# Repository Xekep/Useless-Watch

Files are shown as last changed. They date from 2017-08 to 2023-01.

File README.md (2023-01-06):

Watch the video (https://www.youtube.com/watch?v=YxNCa986Xg4)

# Useless-Watch — Часы c GPS модулем.

## Особенности

* Настройка часового пояса сохраняется в энергонезависимую память часов (часы нет необходимости настраивать при каждом включении).
* Синхронизация времени по GPS происходит раз в час и при смене часового пояса, а также при включении часов.
* В режиме настройки можно выбрать только российские часовые пояса (от +2 — Калининградская область до +12 — Камчатский край).

## Режимы работы

### Настройка часового пояса

Нажатие кнопки №1 переводит часы в режим настройки часового пояса или отображения времени. В режиме настройки на дисплее отображается смещение времени по шкале UTC, а последующие нажатия кнопки №2 приводят к циклическому инкременту часового пояса (от +2 до +12).

### Режим отображения секунд

Нажатие кнопки №2 переводит часы в режим отображения секунд и сантисекунд.

## Электрическая схема

Схема запитывается от 5В и защищена от: перенапряжения, короткого замыкания, переполюсовки.

### Компонентная база

* Макетная плата 5x7см — 3шт.
* Гнездо для ИС — 3шт.
* Гнездо на плату 2.54мм — 4шт.
* Датчик наклона SW-200D — 2шт.
* Защитный диод SA5.0A — 1шт.
* Керамический дисковый конденсатор 0.01мкФ — 1шт.
* Керамический дисковый конденсатор 0.1мкФ — 9шт.
* Керамический дисковый конденсатор 22пФ — 2шт.
* Микроконтроллер ATmega328P-PU — 1шт.
* Модуль GPS NEO6MV2 — 1шт.
* Предохранитель 0.16А — 1шт.
* Разъем Micro-USB DIP — 1шт.
* Резистор 10кОм — 1шт.
* Резистор 1кОм — 8шт.
* Сдвиговый регистр 74HC595 — 2шт.
* Семисегментный индикатор CL5642BH-33 — 1шт.
* Транзистор BS170 — 1шт.
* Угловая тактовая кнопка 3.85мм — 2шт.
* Часовой кварцевый резонатор 32768Гц — 1шт.
* Штырьевая вилка на плату 2.54мм — 4шт.
* Электролитический конденсатор 1000мкФ — 1шт.

## Корпусирование

### Детали корпуса

* Шайба М3 — 24шт.  
* Винт М3 — 8шт.  
* Cтойка для плат М3 10мм — 16шт.  
* Плексиглас

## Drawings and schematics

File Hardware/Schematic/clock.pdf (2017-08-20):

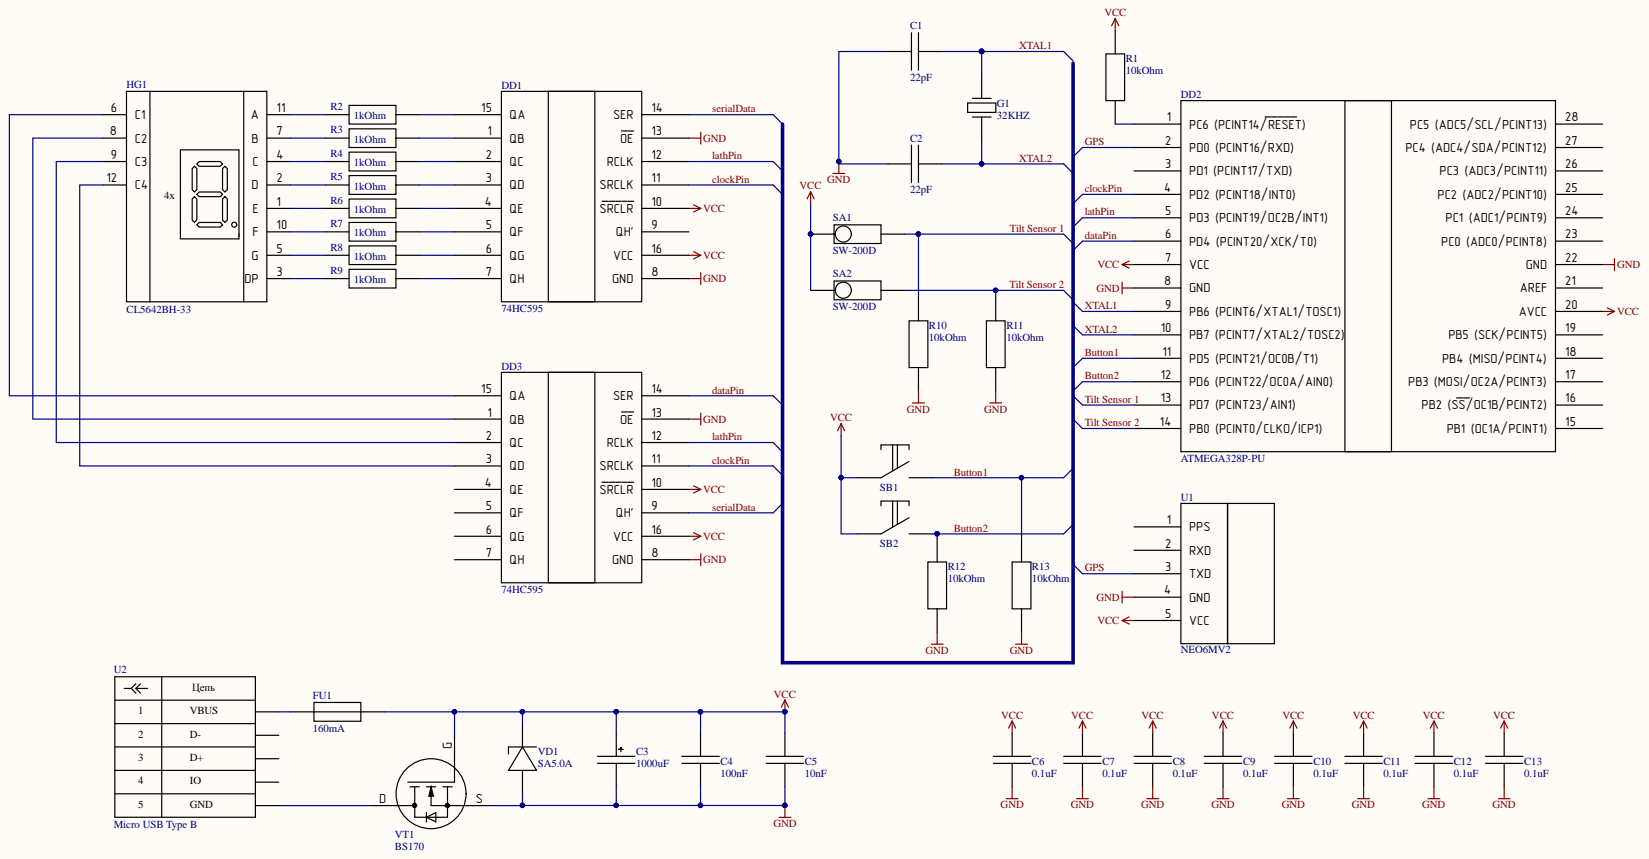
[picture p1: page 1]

C4 12 | | D | 2 | 1kOhm R5 | QD 3

E | 1 | 1kOhm R6 | QE 4 QF 5 QG 6

Цепь

1 | VBUS

5 | GND

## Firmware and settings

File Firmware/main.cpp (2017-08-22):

#include <avr/io.h>
#include <util/delay.h>
#include <avr/interrupt.h>
#include <avr/eeprom.h>
#include <string.h>
#include <stdlib.h>
#include "settings.h"


enum clockMode { clockTime, clockSetTimezone, clockSeconds };
enum displayMode { displayNormal, displayFlipped };
enum segments { A, B, C, D, E, F, G, DP };

uint8_t displayDigits[][4] = { { displayDigit1, displayDigit2, displayDigit3, displayDigit4 },
			       { displayDigit4, displayDigit3, displayDigit2, displayDigit1 } };

uint8_t symbols[][10] = { { zero, one, two, three, four, five, six, seven, eight, nine },
			  { zero_flipped, one_flipped, two_flipped, three_flipped, four_flipped, five_flipped, six_flipped, seven_flipped, eight_flipped, nine_flipped } };

uint8_t hello[][10][4] = {
				{
					{ minus, minus, minus, minus },
					{ symbol_H, minus, minus, minus },
					{ symbol_E, symbol_H, minus, minus },
					{ symbol_L, symbol_E, symbol_H, minus },
					{ symbol_L, symbol_L, symbol_E, symbol_H },
					{ symbol_O, symbol_L, symbol_L, symbol_E },
					{ minus, symbol_O, symbol_L, symbol_L },
					{ minus, minus, symbol_O, symbol_L },
					{ minus, minus, minus, symbol_O },
					{ minus, minus, minus, minus }
				},
				{
					{ minus, minus, minus, minus },
					{ symbol_H_flipped, minus, minus, minus },
					{ symbol_E_flipped, symbol_H_flipped, minus, minus },
					{ symbol_L_flipped, symbol_E_flipped, symbol_H_flipped, minus },
					{ symbol_L_flipped, symbol_L_flipped, symbol_E_flipped, symbol_H_flipped },
					{ symbol_O_flipped, symbol_L_flipped, symbol_L_flipped, symbol_E_flipped },
					{ minus, symbol_O_flipped, symbol_L_flipped, symbol_L_flipped },
					{ minus, minus, symbol_O_flipped, symbol_L_flipped },
					{ minus, minus, minus, symbol_O_flipped },
					{ minus, minus, minus, minus }
				}
			};

uint8_t buffTime[8] = {0xff, 0xff , 0xff, 0xff};
uint8_t buffTimezone[4] = {0xff, 0xff , 0xff, 0xff};

uint8_t currentDisplayMode = displayNormal;
uint8_t currentClockMode = clockTime;
uint8_t EEMEM _timezone = 5;
uint8_t timezone;
uint8_t GPSTimeHour;
uint8_t GPSTimeMin;
uint8_t GPSTimeSec;

char bufferUSART[82];
volatile bool NMEAMessageReceived = false;
volatile bool GPSSynchronizeTime = false;
volatile bool startSyncTime = true;

bool point = false;
bool splash = true;

void shift(uint8_t data);
void splashscreen();
void drawtime();
void drawdigit(uint8_t digit, uint8_t num);
inline void button1Pressed();
inline void button2Pressed();
inline void StartDrawingTimer();
inline void StartClockingTimer();
inline void LoadTimezone();
inline void SaveTimezone();
inline void USART_Init(uint8_t ubrr);
inline void checkTiltSensors();
unsigned char USART_Receive();
bool parseNMEAMessage();
bool CheckGPS();
inline void syncTime();

int main(void)
{	
	uint8_t oldStatePinD = 0;
	uint8_t statePinD = 0;
	uint8_t	delayState = 0;

	// Конфигурируем пины в состояние Output
	DDRD = (1<<clockPin) | (1<<latchPin) | (1<<dataPin);

	// Ощичаем первый сдвиговый регистр
	begin_shift
	shift(0);
	end_shift

	// Инициализация USART 
	USART_Init(MYUBRR);

	// Загрузка часового пояса из EEPROM
	LoadTimezone();

	// Разрешаем общие прерывания
	sei();

	// Запускаем таймер отрисовки
	StartDrawingTimer();

	// Первая синхронизация GPS
	while (!CheckGPS());

	// Запускаем таймер отсчета времени
	StartClockingTimer();

	while (1) 
	{
		CheckGPS();
		
		statePinD = PIND&buttonsPins;

		if (statePinD == oldStatePinD)
		{
			if (delayState < 5)
			delayState++;
			else if (delayState == 5)
			{
				switch(statePinD)
				{
					case button1: button1Pressed(); break;
					case button2: button2Pressed(); break;
				}

				delayState++;
			}
		}
		else
		{
			oldStatePinD = statePinD;
			delayState = 0;
		}
			
		_delay_ms(10);
	}
}

ISR(TIMER2_OVF_vect)
{
	uint8_t static csec = 0;
	uint8_t static sec = 0;
	uint8_t static min = 0;
	uint8_t static hour = 0;
	uint8_t _hour;

	if (GPSSynchronizeTime)
	{
		GPSSynchronizeTime = false;
		hour = GPSTimeHour;
		min = GPSTimeMin;
		sec = GPSTimeSec;
	}

	point ^= true;
	csec += 25;
	if (csec>=100)
	{
		csec = 0;
		sec++;
		if(sec >= 60)
		{
			sec = 0;
			min++;
			if (min >= 60)
			{
				syncTime();
				min = 0;
				hour++;
				if (hour>=24)
				hour = 0;
			}
		}
	}
		
	_hour = hour + timezone;

	if (_hour >= 24) _hour -= 24;

	buffTime[0] = min % 10;
	buffTime[1] = min / 10;

	buffTime[2] = _hour % 10;
	buffTime[3] = _hour / 10;

	buffTime[4] = csec % 10;
	buffTime[5] = csec / 10;

	buffTime[6] = sec % 10;
	buffTime[7] = sec / 10;
}

ISR(TIMER1_COMPA_vect)
{
	checkTiltSensors();

	if (splash)
		splashscreen();
	else
		drawtime();
}

void splashscreen()
{
	static uint8_t currentdigit = 0;
	static uint8_t frame = 0;
	static uint8_t count = 0;

	begin_shift
	shift(~(hello[currentDisplayMode][frame][currentdigit]));
	shift(displayDigits[currentDisplayMode][currentdigit]);
	end_shift

	count++;
	if (count == 40)
	{
		count = 0;
		if(frame == 9)
			splash = false;
		else
			frame++;
	}

	currentdigit++;
	currentdigit &= 3;
}

void drawtime()
{
	static uint8_t currentdigit = 0;

	switch(currentClockMode)
	{
		case clockSeconds: drawdigit(currentdigit, buffTime[currentdigit+4]); break;
		case clockSetTimezone: drawdigit(currentdigit, buffTimezone[currentdigit]); break;
		default: drawdigit(currentdigit, buffTime[currentdigit]); break;
	}

	currentdigit++;
	currentdigit &= 3;
}

void drawdigit(uint8_t digit, uint8_t num)
{
	if (digit>4) return;

	begin_shift
	if (num>9)
		shift(~minus);
	else
		shift(~(symbols[currentDisplayMode][num] | ( currentClockMode != clockSetTimezone && displayDigits[currentDisplayMode][digit] == displayDigit3 && point ? dpoint : 0 )));
	shift(displayDigits[currentDisplayMode][digit]);
	end_shift
}

void shift(uint8_t data)
{
	for (int i = 0; i < 8; i++){
		PORTD &= ~((1<<clockPin)|(1<<dataPin));
		PORTD |= (((data&0x80)>>7)<<dataPin);
		PORTD |= (1<<clockPin);
		data <<= 1;
	}
}

inline void button1Pressed()
{
	currentClockMode = ((currentClockMode == clockTime) ? clockSetTimezone : clockTime);

	if (currentClockMode == clockSetTimezone)
		syncTime();
}

inline void button2Pressed()
{
	switch (currentClockMode)
	{
		case clockTime: currentClockMode = clockSeconds; break;
		case clockSeconds: currentClockMode = clockTime; break;
		case clockSetTimezone: 
			timezone = (timezone == 12) ? 2 : timezone+1;
			SaveTimezone();
			break;
	}
}

inline void StartDrawingTimer()
{
	// Прерывание таймера при совпадении
	TIMSK1 = (1<<OCIE1A);
	// Установка предделителя 1024
	TCCR1B = (1<<CS10)|(1<<CS12)|(1<<WGM12);
	// Установка значения регистра сравнения
	OCR1A = F_CPU/PRESCALER/200;
}

inline void StartClockingTimer()
{
	// Асинхронный режим таймеарц
	ASSR = (1<<AS2);
	// Установка предделителя частоты 32
	TCCR2B |= (1<<CS21) | (1<<CS20);
	// Прерывание таймера по переполнению счетчика
	TIMSK2 |= (1<<TOIE2);
}

inline void LoadTimezone()
{
	timezone = eeprom_read_byte(&_timezone);
	buffTimezone[0] = timezone % 10;
	buffTimezone[1] = timezone / 10;
}

inline void SaveTimezone()
{
	eeprom_write_byte(&_timezone, timezone);
	buffTimezone[0] = timezone % 10;
	buffTimezone[1] = timezone / 10;
}

inline void USART_Init(uint8_t ubrr)
{
	// Установка скорости 
	UBRR0H = ubrr >> 8;
	UBRR0L = ubrr & 0xFF;
	// Разрешение приема, передачи данных и
	// прерывания по завершению приема данных
	UCSR0B = (1<<RXEN0)|(1<<RXCIE0);
	// Установка режима работы USART: асинхронный, размер данных 8 бит,
	//  1 стоп бит, бит четности выключен
	UCSR0C = (3<<UCSZ00);
}

 inline bool parseNMEAMessage()
{
	uint8_t length = 0;
	uint8_t checkSum = 0;
	uint8_t _checkSum = 0;
	char* pTime = NULL;

	if (bufferUSART[0] == '$')
	{
		length = (uint8_t)strlen(bufferUSART);
		
		if (length > 10)
		{
			if (strstr(bufferUSART, "$GPGGA") != NULL ||
				strstr(bufferUSART, "$GPRMC") != NULL)
			{
				checkSum = strtoul(&bufferUSART[length-2], NULL, 16);
			
				if (checkSum != 0)
				{
					// Время
					pTime = strstr(bufferUSART, ",");
					
					if (pTime != NULL)
					{
						pTime++;

						for (uint8_t i = 0; i<6; i++)
						{
							if (pTime[i] < '0' || pTime[i] > '9')
								return false;
						}

						GPSTimeHour = (pTime[0]-'0')*10+(pTime[1]-'0');
						GPSTimeMin = (pTime[2]-'0')*10+(pTime[3]-'0');
						GPSTimeSec = (pTime[4]-'0')*10+(pTime[5]-'0');

						// Подсчет контрольной суммы между $ и *
						for (int i = 1; i < length-3; i++) {
							_checkSum ^= bufferUSART[i];
						}

						if (_checkSum == checkSum)
							return true;
					}
				}
			}
		}
	}
	return false;
}

inline void syncTime()
{
	NMEAMessageReceived = false;
	startSyncTime = true;
}

inline void checkTiltSensors()
{
	if (!tiltSensor1)
	{
		if (tiltSensor2)
			currentDisplayMode = displayNormal;
	}
	else
	{
		if(!tiltSensor2)
			currentDisplayMode = displayFlipped;
	}
}

bool CheckGPS()
{
	if (!startSyncTime) return false;

	if (!NMEAMessageReceived) return false;

	if (parseNMEAMessage())
	{
		startSyncTime = false;
		GPSSynchronizeTime = true;
		return true;
	}
	else
	{
		NMEAMessageReceived = false;
		return false;
	}
}

ISR(USART_RX_vect)
{
	static uint8_t bufferCount = 0;
	char data = UDR0;
	
	if (!NMEAMessageReceived)
	{
		if (bufferCount >= sizeof(bufferUSART))
			bufferCount = 0;
		
		if (data == '$')
		{
			bufferCount = 0;
			bufferUSART[bufferCount] = data;
			bufferCount++;
		}
		else if (data == '\r')
		{
			bufferUSART[bufferCount] = 0;
			bufferCount = 0;
			NMEAMessageReceived = true;
		}
		else
		{
			bufferUSART[bufferCount] = data;
			bufferCount++;
		}
	}
}

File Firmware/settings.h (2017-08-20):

#ifndef SETTINGS_H_
#define SETTINGS_H_

#define BAUD 9600
#define MYUBRR F_CPU/16UL/BAUD-1

#define begin_shift PORTD &= ~(1<<latchPin);
#define end_shift PORTD |= (1<<latchPin);

#define PRESCALER 1024 // Предделитель

#define clockPin	PD2		// Тактовый вход
#define latchPin	PD3		// Защелка
#define dataPin		PD4		// Данные
#define button1  1<<PD5		// Кнопка режима настройки часового пояса
#define button2  1<<PD6		// Кнопка режима отображения секунд
#define buttonsPins (button1 | button2)
#define tiltSensor1 (PIND>>PD7)&1
#define tiltSensor2 (PINB>>PB0)&1

#define minus			(1<<G)
#define dpoint			(1<<DP)

#define zero			(1<<A)|(1<<B)|(1<<C)|(1<<D)|(1<<E)|(1<<F)
#define one				(1<<B)|(1<<C)
#define two				(1<<A)|(1<<B)|(1<<D)|(1<<E)|(1<<G)
#define three			(1<<A)|(1<<B)|(1<<C)|(1<<D)|(1<<G)
#define four			(1<<B)|(1<<C)|(1<<F)|(1<<G)
#define five			(1<<A)|(1<<C)|(1<<D)|(1<<F)|(1<<G)
#define six				(1<<A)|(1<<C)|(1<<D)|(1<<E)|(1<<F)|(1<<G)
#define seven			(1<<A)|(1<<B)|(1<<C)
#define eight			(1<<A)|(1<<B)|(1<<C)|(1<<D)|(1<<E)|(1<<F)|(1<<G)
#define nine			(1<<A)|(1<<B)|(1<<C)|(1<<D)|(1<<F)|(1<<G)

#define zero_flipped	zero
#define one_flipped		(1<<E)|(1<<F)
#define two_flipped		two
#define	three_flipped	(1<<A)|(1<<D)|(1<<E)|(1<<F)|(1<<G)
#define four_flipped	(1<<C)|(1<<E)|(1<<F)|(1<<G)
#define five_flipped	five
#define six_flipped		nine
#define seven_flipped	(1<<D)|(1<<E)|(1<<F)
#define eight_flipped	eight
#define nine_flipped	six

#define symbol_H		(1<<B)|(1<<C)|(1<<E)|(1<<F)|(1<<G)
#define symbol_E		(1<<A)|(1<<D)|(1<<E)|(1<<F)|(1<<G)
#define symbol_L		(1<<D)|(1<<E)|(1<<F)
#define symbol_O		zero

#define symbol_H_flipped	symbol_H
#define symbol_E_flipped	three
#define symbol_L_flipped	seven
#define symbol_O_flipped	zero

#define displayDigit1		1<<0
#define displayDigit2		1<<1
#define displayDigit3		1<<2
#define displayDigit4		1<<3

#endif 
